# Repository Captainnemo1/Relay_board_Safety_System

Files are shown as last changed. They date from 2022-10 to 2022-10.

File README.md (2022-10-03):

# Relay_board_Safety_System
This is repo containing the design details for constructing a relay board with CAN integration

I created a relay system that is driven by an Atmega32u4 and has CANBUS compatibility.
An Atmega32u4 is used to power the relay box and track the status of the shutdown systems. The relay box is also connected to the CAN bus using the MCU. This allows us to communicate the fault to the driver via the driver interface and allows the vehicle's control systems to be aware of the shutdown state as well.

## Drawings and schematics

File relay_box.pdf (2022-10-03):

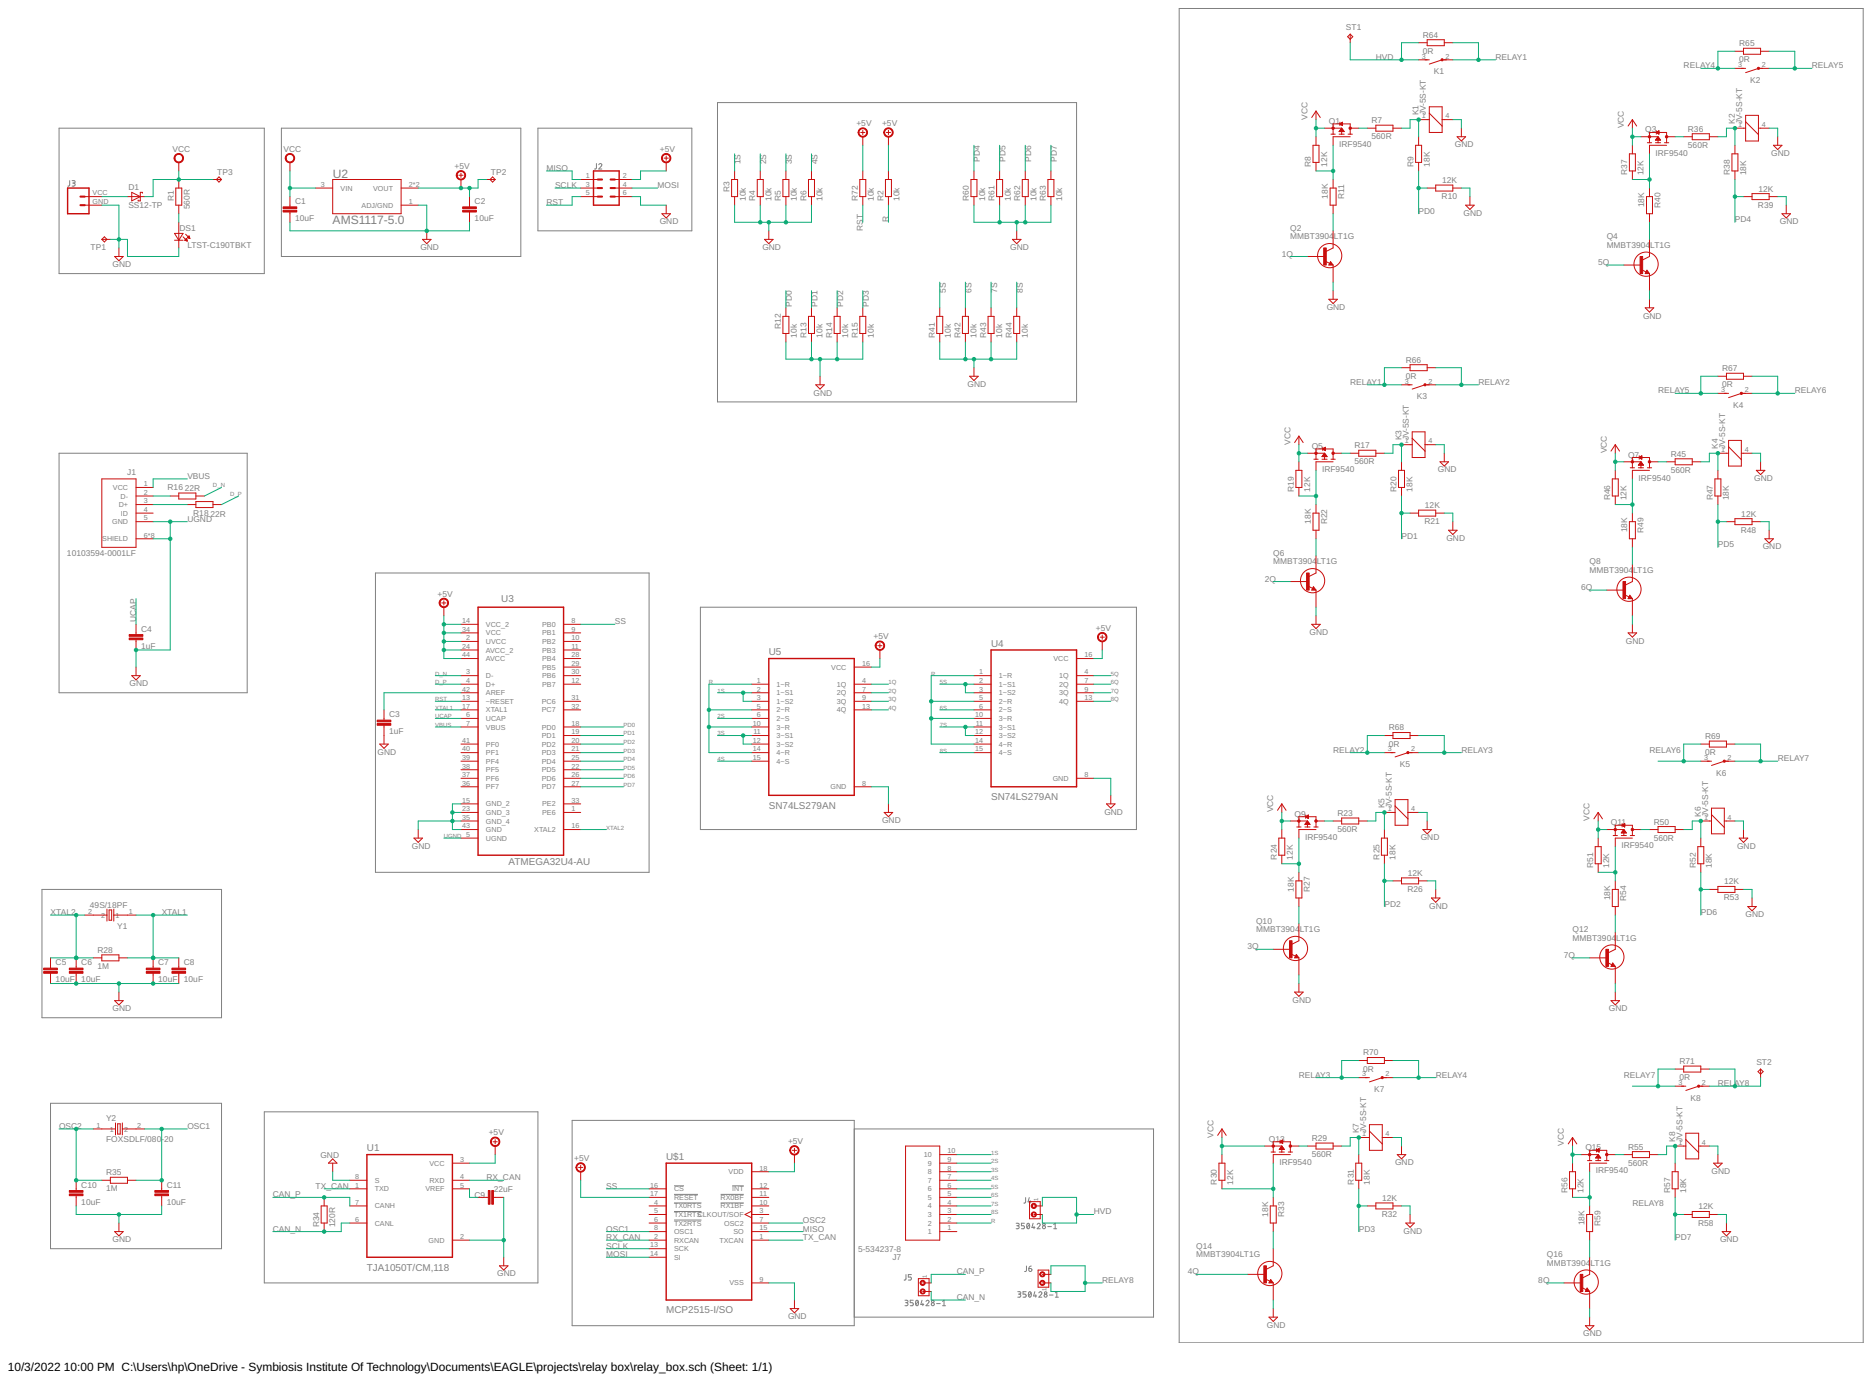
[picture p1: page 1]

10/3/2022 10:00 PM C:\Users\hp\OneDrive - Symbiosis Institute Of Technology\Documents\EAGLE\projects\relay box\relay_box.sch (Sheet: 1/1)

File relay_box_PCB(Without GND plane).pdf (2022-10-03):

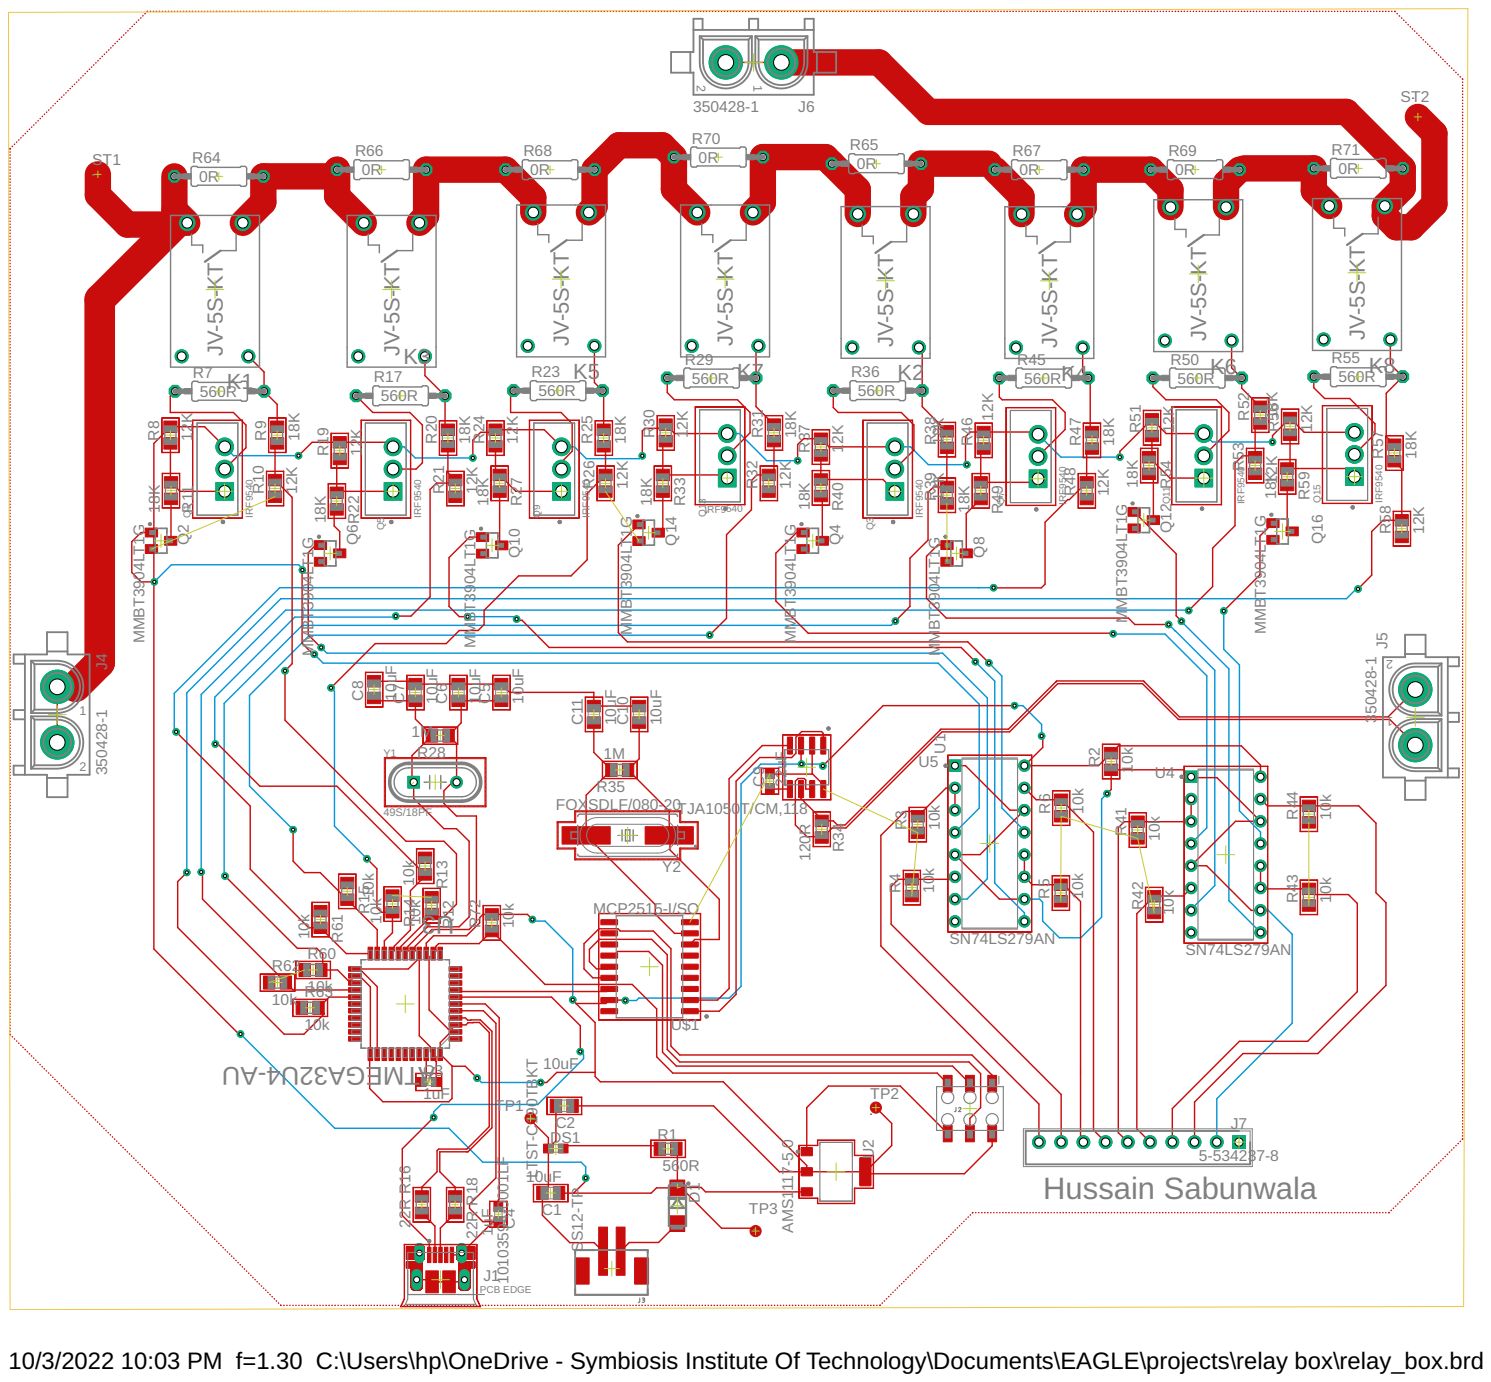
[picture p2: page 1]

10/3/2022 10:03 PM f=1.30 C:\Users\hp\OneDrive - Symbiosis Institute Of Technology\Documents\EAGLE\projects\relay box\relay_box.brd

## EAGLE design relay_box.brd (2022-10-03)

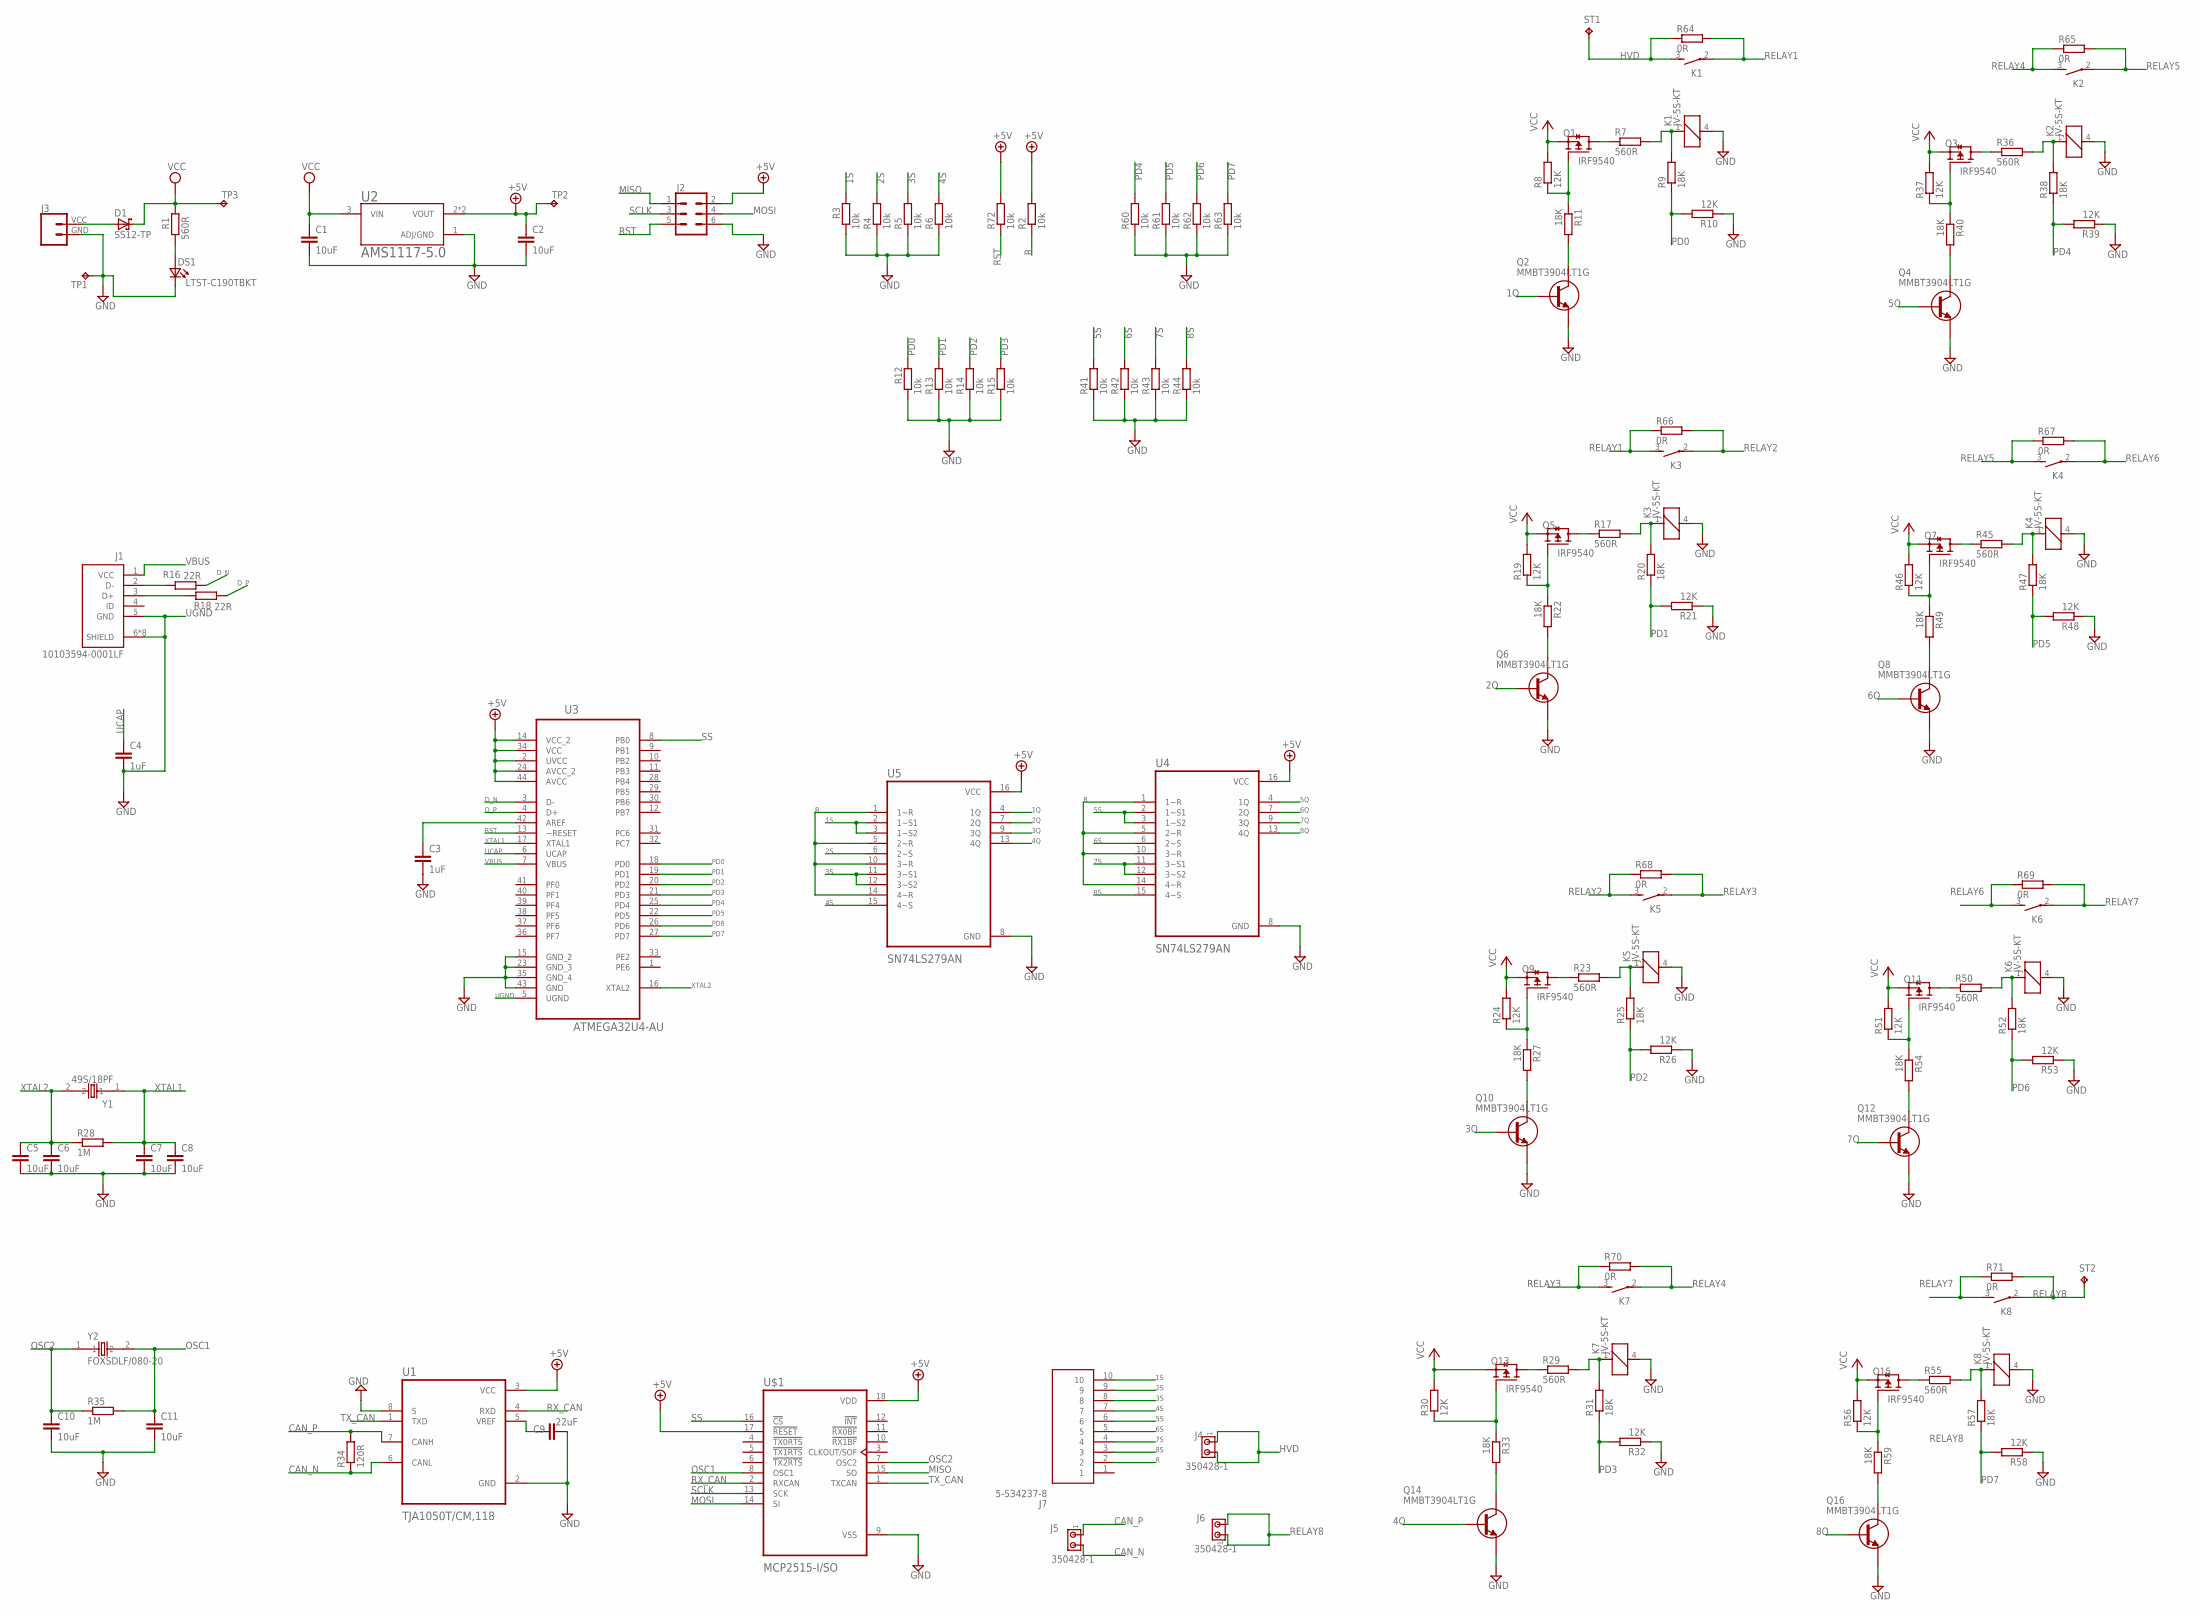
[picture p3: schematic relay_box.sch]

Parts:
C1, C2, C5, C6, C7, C8, C10, C11: 10uF; C0805
C3, C4: 1uF; C0603
C9: 22uF; C0603
D1: SS12-TP; DO214AC
DS1: LTST-C190TBKT; 0603
J1: 10103594-0001LF; AMPHENOL_10103594-0001LF
J2: CONN_03X2FEMALE_SMD; 2X3_SMD
J3: CONN_024UCON-15767; JST-2-SMD-VERT
J4, J5, J6: 350428-1
J7: 5-534237-8; RHDR10W76P0X254_1X10_2540X356X
K1, K2, K3, K4, K5, K6, K7, K8: JV-5S-KT; JV-KT
Q1, Q3, Q5, Q7, Q9, Q11, Q13, Q15: IRF9540; TO254P1052X465X1989-3
Q2, Q4, Q6, Q8, Q10, Q12, Q14, Q16: MMBT3904LT1G; SOT23
R1: 560R; R0805
R2, R3, R4, R5, R6, R12, R13, R14, R15, R41, R42, R43, R44, R60, R61, R62, R63, R72: 10k; R0805
R7, R17, R23, R29, R36, R45, R50, R55: 560R; 0207/10
R8, R10, R19, R21, R24, R26, R30, R32, R37, R39, R46, R48, R51, R53, R56, R58: 12K; R0805
R9, R11, R20, R22, R25, R27, R31, R33, R38, R40, R47, R49, R52, R54, R57, R59: 18K; R0805
R16, R18: 22R; R0805
R28, R35: 1M; R0805
R34: 120R; R0805
R64, R65, R66, R67, R68, R69, R70, R71: 0R; 0207/10
ST1, ST2: TPB1,27; B1,27
TP1, TP2, TP3: TPB1,27; B1,27
U1: TJA1050T/CM,118; SOIC127P600X175-8N
U2: AMS1117-5.0; SOT229P700X180-4N
U3: ATMEGA32U4-AU; QFP80P1200X1200X120-44N
U4, U5: SN74LS279AN; DIP794W45P254L1969H508Q16
U$1: MCP2515-I/SO; SOIC127P1030X265-18N
Y1: 49S/18PF; XTAL_49S/18PF
Y2: FOXSDLF/080-20; XTAL1170X500X450

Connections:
1Q: Q2.1 (B), U5.4 (1Q)
1S: J7.10, R3.2, U5.2 (1~S1), U5.3 (1~S2)
2Q: Q6.1 (B), U5.7 (2Q)
2S: J7.9, R4.2, U5.6 (2~S)
3Q: Q10.1 (B), U5.9 (3Q)
3S: J7.8, R5.2, U5.11 (3~S1), U5.12 (3~S2)
4Q: Q14.1 (B), U5.13 (4Q)
4S: J7.7, R6.2, U5.15 (4~S)
5Q: Q4.1 (B), U4.4 (1Q)
5S: J7.6, R41.2, U4.2 (1~S1), U4.3 (1~S2)
6Q: Q8.1 (B), U4.7 (2Q)
6S: J7.5, R42.2, U4.6 (2~S)
7Q: Q12.1 (B), U4.9 (3Q)
7S: J7.4, R43.2, U4.11 (3~S1), U4.12 (3~S2)
8Q: Q16.1 (B), U4.13 (4Q)
8S: J7.3, R44.2, U4.15 (4~S)
+5V: C2.1, J2.2, R2.2, R72.2, TP2.TP, U1.3 (VCC), U2.2 (VOUT), U2.4 (VOUT), U3.2 (UVCC), U3.14 (VCC_2), U3.24 (AVCC_2), U3.34 (VCC), U3.44 (AVCC), U4.16 (VCC), U5.16 (VCC), U$1.17 (!RESET)
CAN_N: J5.2, R34.1, U1.6 (CANL)
CAN_P: J5.1, R34.2, U1.7 (CANH)
D_N: R16.1, U3.3 (D-)
D_P: R18.1, U3.4 (D+)
GND: C1.2, C2.2, C3.2, C5.2, C6.2, C7.2, C8.2, C9.2, C10.2, C11.2, DS1.1 (K2), J2.6, J3.GND (1), K1.4 (2), K2.4 (2), K3.4 (2), K4.4 (2), K5.4 (2), K6.4 (2), K7.4 (2), K8.4 (2), Q2.2 (E), Q4.2 (E), Q6.2 (E), Q8.2 (E), Q10.2 (E), Q12.2 (E), Q14.2 (E), Q16.2 (E), R3.1, R4.1, R5.1, R6.1, R10.1, R12.1, R13.1, R14.1, R15.1, R21.1, R26.1, R32.1, R39.1, R41.1, R42.1, R43.1, R44.1, R48.1, R53.1, R58.1, R60.1, R61.1, R62.1, R63.1, TP1.TP, U1.2 (GND), U1.8 (S), U2.1 (ADJ/GND), U3.15 (GND_2), U3.23 (GND_3), U3.35 (GND_4), U3.43 (GND), U4.8 (GND), U5.8 (GND), U$1.9 (VSS)
HVD: J4.1, J4.2, K1.3 (S), R64.1, ST1.TP
MISO: J2.1, U$1.15 (SO)
MOSI: J2.4, U$1.14 (SI)
unnamed: Q1.1 (G), R8.1, R11.1
unnamed: Q1.2 (D), R7.1
unnamed: Q2.3 (C), R11.2
unnamed: K1.1, R7.2, R9.2
unnamed: Q3.1 (G), R37.1, R40.1
unnamed: Q4.3 (C), R40.2
unnamed: K2.1, R36.2, R38.2
unnamed: Q3.2 (D), R36.1
unnamed: Q5.1 (G), R19.1, R22.1
unnamed: Q6.3 (C), R22.2
unnamed: K3.1, R17.2, R20.2
unnamed: Q5.2 (D), R17.1
unnamed: Q7.1 (G), R46.1, R49.1
unnamed: Q8.3 (C), R49.2
unnamed: K4.1, R45.2, R47.2
unnamed: Q7.2 (D), R45.1
unnamed: Q9.1 (G), R24.1, R27.1
unnamed: Q10.3 (C), R27.2
unnamed: K5.1, R23.2, R25.2
unnamed: Q9.2 (D), R23.1
unnamed: Q11.1 (G), R51.1, R54.1
unnamed: Q12.3 (C), R54.2
unnamed: K6.1, R50.2, R52.2
unnamed: Q11.2 (D), R50.1
unnamed: Q13.1 (G), R30.1, R33.1
unnamed: Q14.3 (C), R33.2
unnamed: K7.1, R29.2, R31.2
unnamed: Q13.2 (D), R29.1
unnamed: Q15.1 (G), R56.1, R59.1
unnamed: Q16.3 (C), R59.2
unnamed: K8.1, R55.2, R57.2
unnamed: Q15.2 (D), R55.1
unnamed: DS1.2 (A2), R1.1
unnamed: D1.A, J3.VCC (2)
unnamed: J1.2 (D-), R16.2
unnamed: J1.3 (D+), R18.2
unnamed: C9.1, U1.5 (VREF)
unnamed: C3.1, U3.42 (AREF)
OSC1: C11.1, R35.2, U$1.8 (OSC1), Y2.2
OSC2: C10.1, R35.1, U$1.7 (OSC2), Y2.1
PD0: R9.1, R10.2, R12.2, U3.18 (PD0)
PD1: R13.2, R20.1, R21.2, U3.19 (PD1)
PD2: R14.2, R25.1, R26.2, U3.20 (PD2)
PD3: R15.2, R31.1, R32.2, U3.21 (PD3)
PD4: R38.1, R39.2, R60.2, U3.25 (PD4)
PD5: R47.1, R48.2, R61.2, U3.22 (PD5)
PD6: R52.1, R53.2, R62.2, U3.26 (PD6)
PD7: R57.1, R58.2, R63.2, U3.27 (PD7)
R: J7.2, R2.1, U4.1 (1~R), U4.5 (2~R), U4.10 (3~R), U4.14 (4~R), U5.1 (1~R), U5.5 (2~R), U5.10 (3~R), U5.14 (4~R)
RELAY1: K1.2, K3.3 (S), R64.2, R66.1
RELAY2: K3.2, K5.3 (S), R66.2, R68.1
RELAY3: K5.2, K7.3 (S), R68.2, R70.1
RELAY4: K2.3 (S), K7.2, R65.1, R70.2
RELAY5: K2.2, K4.3 (S), R65.2, R67.1
RELAY6: K4.2, K6.3 (S), R67.2, R69.1
RELAY7: K6.2, K8.3 (S), R69.2, R71.1
RELAY8: J6.1, J6.2, K8.2, R71.2, ST2.TP
RST: J2.5, R72.1, U3.13 (~RESET)
RX_CAN: U1.4 (RXD), U$1.2 (RXCAN)
SCLK: J2.3, U$1.13 (SCK)
SS: U3.8 (PB0), U$1.16 (!CS)
TX_CAN: U1.1 (TXD), U$1.1 (TXCAN)
UCAP: C4.1, U3.6 (UCAP)
UGND: C4.2, J1.5 (GND), J1.6 (SHIELD), J1.7 (SHIELD), J1.8 (SHIELD), J1.9 (SHIELD), J1.10 (SHIELD), J1.11 (SHIELD), J1.S1 (SHIELD), J1.S2 (SHIELD), U3.5 (UGND)
VBUS: J1.1 (VCC), U3.7 (VBUS)
VCC: C1.1, D1.C, Q1.3 (S), Q3.3 (S), Q5.3 (S), Q7.3 (S), Q9.3 (S), Q11.3 (S), Q13.3 (S), Q15.3 (S), R1.2, R8.2, R19.2, R24.2, R30.2, R37.2, R46.2, R51.2, R56.2, TP3.TP, U2.3 (VIN)
XTAL1: C7.1, C8.1, R28.2, U3.17 (XTAL1), Y1.1
XTAL2: C5.1, C6.1, R28.1, U3.16 (XTAL2), Y1.2

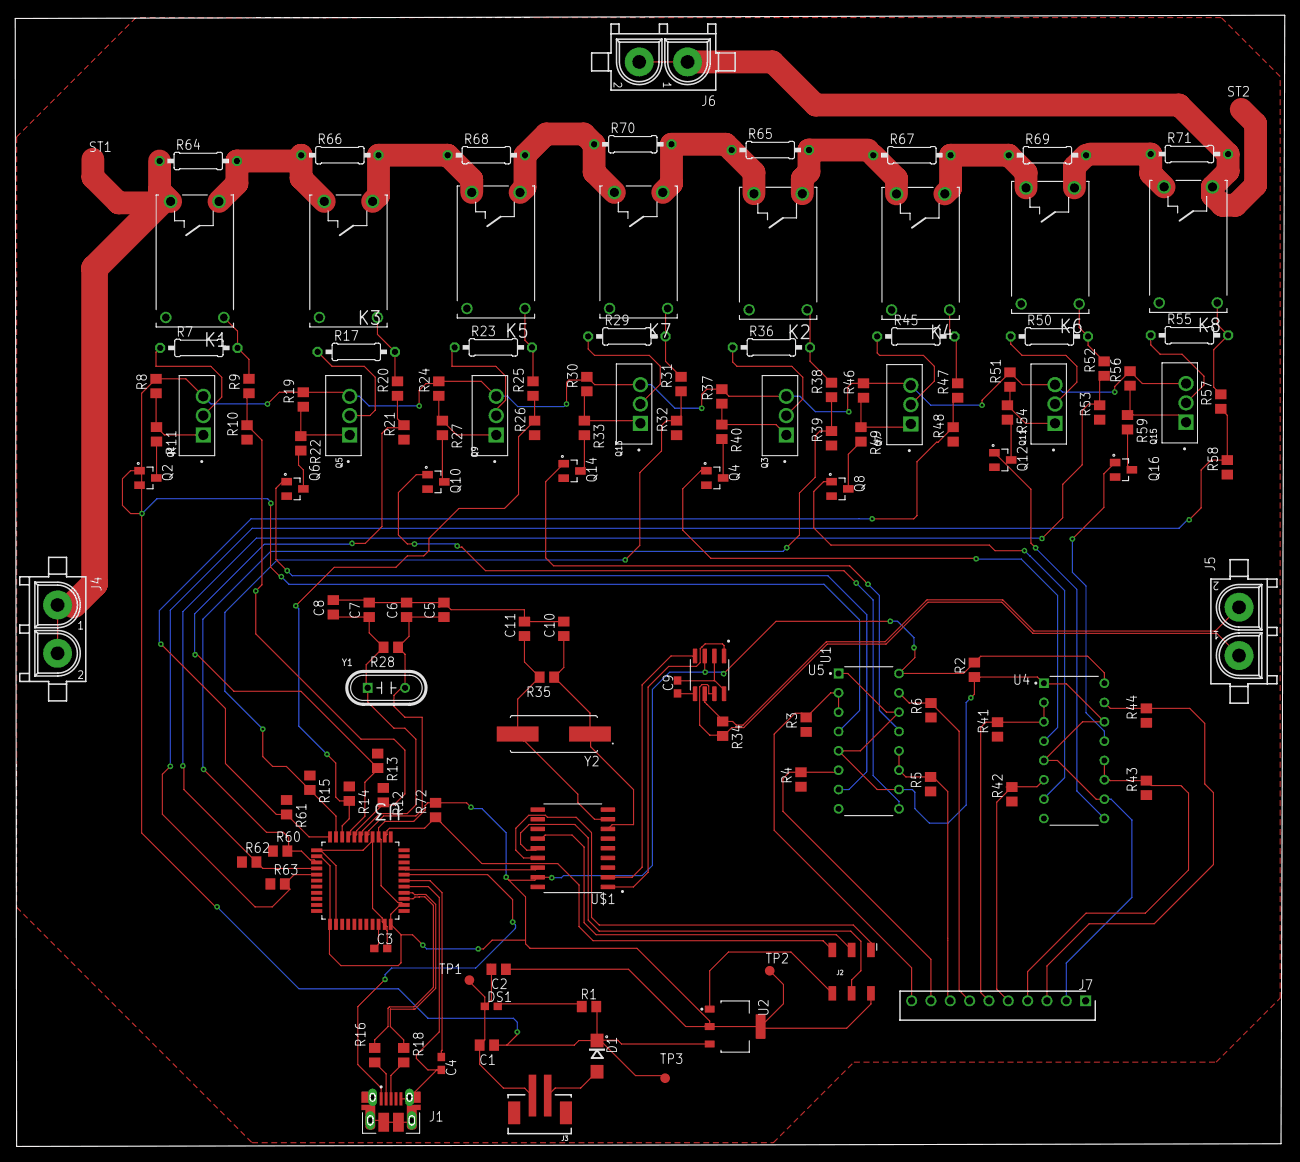
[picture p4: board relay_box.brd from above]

Board: 2 copper layers, 166.8 x 148.6 mm, 129 parts (0 on the bottom side), 93 nets.

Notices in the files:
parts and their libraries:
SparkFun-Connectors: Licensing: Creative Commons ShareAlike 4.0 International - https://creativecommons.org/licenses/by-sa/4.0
